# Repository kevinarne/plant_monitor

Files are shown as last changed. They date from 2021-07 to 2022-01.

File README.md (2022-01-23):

# Purpose
As I seek to both improve the lives of my plants and learn more about Python development, I've decided to start instrumenting my plants with some sensors like light and weight sensors.

# Current State
There are three kinds of sensors currently supported: CdS light sensor hooked up to an Arduino (directly connected to Pi via serial), CdS light sensor hooked up to an ESP32 (wireless), and load cell hooked up to an ESP32 (wireless). Each of these connects to a Raspberry Pi-hosted MySQL database on my local network.

The wireless sensors add data to the database via an HTTP request handled by a PHP script on the local server. The wired sensor is polled via serial regularly by a python script scheduled with crontab.

# Current Event Types
* 10-bit CdS light sensor (wired Arduino Nano)
* 12-bit CdS light sensor (wireless ESP32)
* Manual weighing
* Load cell weighing (wireless ESP32)
* Wiring (for shaping trees)
* Removed wire
* Root pruning
* Plant status (out of 5 stars)

# Potential Next Steps
* Visualize the collected light sensor data
* Create more ESP32-powered sensors
* Migrate from serial light sensor to ESP32 light sensor
* Add a user id column to the plant_events, sensors, and plants tables
* Convert to Flask
* Add web page to store wireless connections to ESP32 sketches
* Store tare value in EEPROM on ESP32

# Flask Conversion Next Steps
* Create routes.py
* Migrate database to an sqlite database
* Create user database
* Create web interface for adding weight
* Create plant status page
* 

# Current Tables
* plant_events - Tracks values recorded by various sensors, their associated plants, and things like watering, repotting, pruning, weighing, and even light. Currently it only tracks light.
* plants - Dictionary relating ids used in plant_events and actual plants.
* event_codes - Dictionary correlating events with unique ids.
* sensors - Details of the sensors.

# Set Up
Python 3 Libraries:
* datetime
* itertools
* python-decouple
* pyserial
* pymysql
* matplotlib
* numpy
* smtplib

See /setup/README.md for more details on setting up this project, including database setup.

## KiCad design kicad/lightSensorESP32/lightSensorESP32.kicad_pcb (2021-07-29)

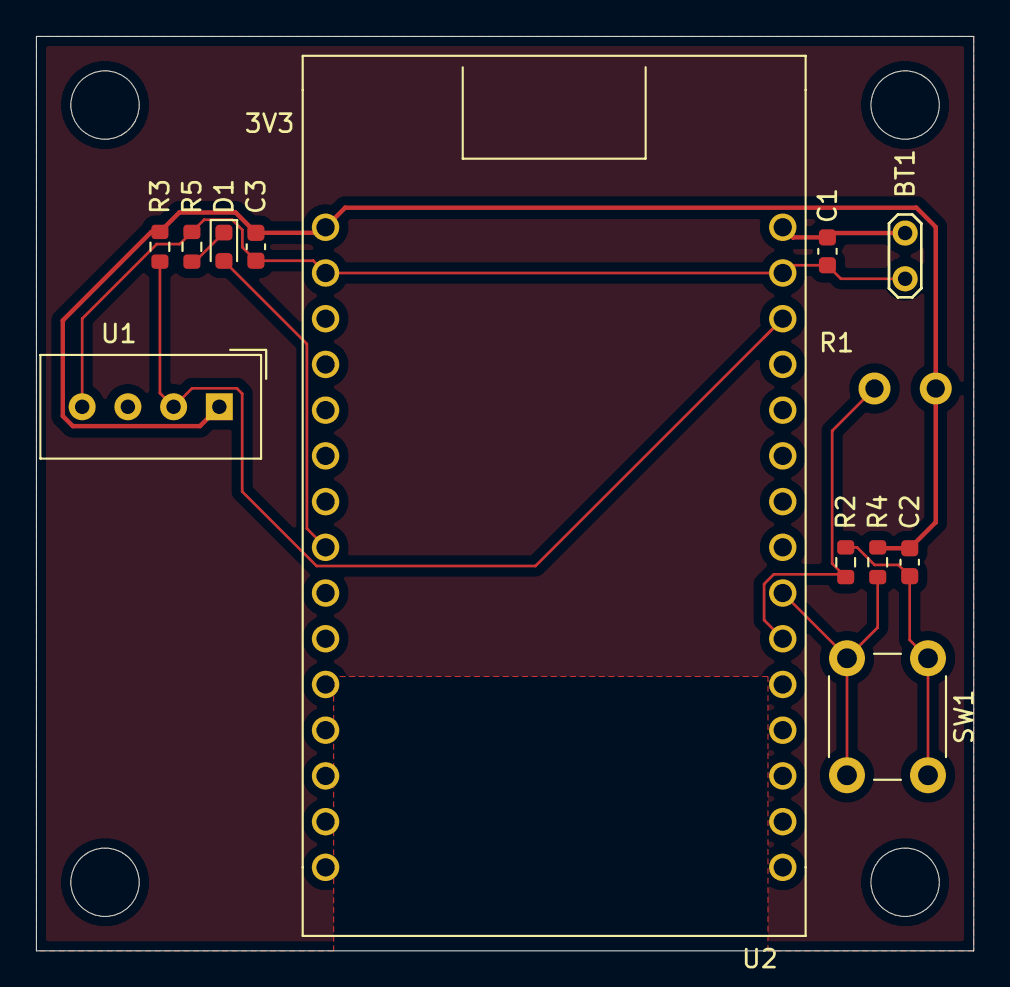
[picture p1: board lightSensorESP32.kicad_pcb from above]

Board: 2 copper layers, 52.1 x 50.8 mm, 13 parts (0 on the bottom side), 8 nets.

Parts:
BT1: Battery_Cell; TestPoint_2Pads_Pitch2.54mm_Drill0.8mm
C1, C2, C3: CAP; C_0603_1608Metric
D1: LED; LED_0603_1608Metric
R1: R_PHOTO; CdS_Adafruit
R2, R3, R4, R5: R_Small_US; R_0603_1608Metric
SW1: SW_Push; SW_PUSH_6mm_H4.3mm
U1: DHT11; Aosong_DHT11_5.5x12.0_P2.54mm
U2: ESP32-BO

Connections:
+3V3: C2.1, C3.1, R1.1, R3.1, R4.2, U1.1, U2.1
DHT: R3.2, U1.2, U2.28
GND: BT1.2, C1.2, C2.2, C3.2, R2.2, R5.1, SW1.1, U1.4, U2.2, U2.29
LED: D1.2, U2.8
LGHT: R1.2, R2.1, U2.21
unnamed: D1.1, R5.2
SWT: R4.1, SW1.2, U2.22
VCC: BT1.1, C1.1, U2.30

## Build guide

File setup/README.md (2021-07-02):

# Required libraries
* mariadb
* pymysql
* datetime

# Initializing the database
Start by updating your pi:
* sudo apt update
* sudo apt upgrade

Install the server software
* sudo apt install mariadb-server

# Install the Python module:
pip3 install mariadb

# Run secure installation (set up root password)
sudo mysql_secure_installation
* set a password
* remove anonymous users
* disallow root login remotely
* remove the test database
* reload privileges

# Create new user
* sudo mysql -uroot -p
* CREATE DATABASE <dbname>;
* CREATE USER '<username>'@'localhost' IDENTIFIED BY '<password>';
* GRANT ALL PRIVILEGES ON <dbname>.* TO '<username>'@'localhost';

or for a remote user:
* GRANT ALL PRIVILEGES on <dbname>.* TO '<username>'@'%';
* FLUSH PRIVILEGES;

# Add your credentials to a .env file in your root directory
While in the util folder:
* nano .env
* HOST_NAME=yourhostname
* USER_NAME=yourusername
* PASSWORD=yourpassword
* Replace the right side of each of the above 3 lines with whatever your values are.

# Initialize the tables
Run util/setup.py from the util folder.

You're all set.

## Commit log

2021-05-03 Added an integer conversion to the raw data off of the Arduino.
2021-05-03 Added menu that allows me to choose to read the sensor or exit
2021-05-04 Added setup README.md to help me remember how to set up the database in case things go sideways.
2021-05-05 Added ability to log a light sensor reading to the database in main.py. Next steps are to add regular recording and clean up the code base. Input validation and credentials need to be sorted out.
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2021-05-16 Added some rough files for expanding the scope of the data I collect. Currently I'm planning on two additional classes to capture the kinds of plants I currently have and the events that might happen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
2021-05-24 Added a basic script for adding plants to the plant table. Currently it just establishes a database connection and asks the user for the plant name and notes. Next step is to actually add that data t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
2021-05-25 Renamed main.py to read_light.py to transition to calling a centralized sensor polling script and reserve main for user-facing activities like visualizing data or adding new plants.
2021-05-27 Added create tables function to sqlmanager to create all of the necessary tables in the database. Next step is to transition all of the values in the light_val table to the plant_events table. That's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
2021-05-28 Added a menu option for adding sensors (though it isn't connected to anything yet) in main. Eliminated some print statements from sqlmanager.py.
2021-05-30 Implemented adding sensors using the main.py menu. Ran into trouble providing the wrong kind of data for the table, which wasn't surfaced in my error messages.
2021-05-31 Started the creation of a script to migrate the light values from the old light table to the new plant_event table to more effectively capture the data coming off of a variety of sensors.
2021-05-31 Script for migrating to the event table is ready once one line is uncommented. Next up is re-directing the sensor polling to save the data in the plant_events table.
2021-06-05 Added option in main to manually add event_codes. Currently just takes in a description and truncates it. Still needs to actually interface with the database.
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2021-06-08 Added script to take a csv of my current plant weights and add it to the plant_events table.
2021-06-14 Added some next steps to README.md. Removed last watered option in the menu (deprecated by plant status). Removed successful prints from sqlmanager.py.
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2021-06-24 Set up an ESP32 to send basic HTTP requests that interface with the newly-created remotelight.php. Next up is fleshing out the php script to add data from the ESP32 to the database.
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2021-06-24 Created wireframe with comments for a page that displays all of the plant statuses.
2021-06-24 Implemented plant status in php so I can now access the plant statuses from my phone easily. This page details when each plant was last watered, at what weight, and what the current weight is.
2021-06-26 Fleshed out php page for adding a light sensor's readings to the database. Currently iterates through the appropriate plants and adds dummy data. Needs to be changed to add real data.
2021-06-27 Adding light data to the database remotely isn't currently working. Appears to be failing at the line where the data is actually added to the database.
2021-06-28 Removed old light sensor script for a wireframe one that runs on an ESP32 and connects wirelessly to the database.
2021-06-28 Previous commit omitted the line in the main loop that actually polled the sensor. This has been fixed.
2021-06-29 Changed remotelight.php to use GET instead of POST for ease of coding on the ESP32.
2021-06-29 Tweaked ESP32 script to make it slightly easier to adapt to other sensor types.
2021-07-01 Updated next steps in README.md. Improved Arduino script to read light sensor.
2021-07-01 Updated light sensor script to allow for configurable sensor and event ids.
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2021-07-03 Updated the weight Arduino script to use the remotelight.php script for inputting values.
2021-07-05 Added a return to the execute_mysql. Created a check sensors scripts to export the most recent entry under each sensor.
2021-07-05 Made some minor tweaks to the sensor checker script. Currently the serial light sensor isn't being added to the database correctly. Need to design a PCB to make it easier to wire up new light sensors.
2021-07-07 Started schematic for a board to simplify wiring light sensors. May choose to include humidity and temperature sensors too to round out a weather sensor station.
    [lightSensorESP32.kicad_pcb, lightSensorESP32.sch]
2021-07-08 Removed status LED from light sensor schematic since there's already a status LED on the ESP32 breakout board. Also started to create the schematic symbol for the ESP32 breakout board.
    [lightSensorESP32.sch]
2021-07-10 Started script to visualize differences between the weight sensor and manually recorded weight.
2021-07-10 Running into some incompatibilities between the ways datetimes are being encoded by the manual records and weight sensor. I can tweak the existing data to work with the current script, but I should a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
2021-07-12 Added some datetime string handling adjustments to the checksensors script to handle discrepencies between the time reporting of different sensors.
2021-07-16 Added DHT11 and ESP32 to light sensor schematic.
    [lightSensorESP32.sch]
2021-07-17 Added ESP32 layout to light sensor board.
    [lightSensorESP32.sch]
2021-07-20 Fixed time overlap problem in visualization script. X values were not previously converted to datetime objects. Created a short function to narrow the range of dates displayed to the start of the sen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
2021-07-21 Updated check sensors script to send emails when it has been more than a day since the sensor checked in.
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2021-07-22 Really struggling with the weight Arduino script. Core problem is loading the network credentials from Preferences and converting them to the right form for the WiFi library.
2021-07-22 Removed Arduino scripts from this repository. They will be moved to a different repo that I'll post shortly.
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2021-07-28 Added LED and switch to light sensor schematic. Next up is laying out the board.
    [lightSensorESP32.kicad_pcb, lightSensorESP32.sch]
2021-07-29 Routed light, temperature, and humidity board and sent it off to be printed.
    [lightSensorESP32.kicad_pcb, lightSensorESP32.sch]
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
